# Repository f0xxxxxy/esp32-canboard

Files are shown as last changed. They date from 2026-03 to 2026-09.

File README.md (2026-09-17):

# ESP32-CANBoard
* ESP32-S3 Dual Core SoC
* MCP2562T CAN Transceiver (up to 1Mbps)
* 16x 5V tolerant analog inputs via 2x ADS7830 I2C expanders.
* Optional pull-up resistors via fused 5V rail for each input (TH 6.3mm).
* 3x 5V power output pins for digital sensors.
  * 500ma self-resetting thermal fuse.
  * Output pins and pull-up rail only active with external power present, not USB.
* USB-C for programming, with JTAG support for debugging.
* ESD Protection on both USB and CAN, with reverse polarity protection on power input.
* TE Connectivity AMP 26 Way Superseal Connector.
  * PCB Socket: 9-6437287-8
  * Cable Plug: 3-1437290-7
* Internal 5V rail reference for accurate output calculation when pull-up in use.
* Configuration via web interface over WiFi, with backup and restore functionality.
* Optional per-channel median filtering with selectable strength (none/low/med/high) to reduce noise.

## Device Configuration

On each boot the board enables a WiFi access point and web configuration interface; this will automatically disable after 120 seconds if no client connects.

| SSID | WPA2 Key | Web UI |
|:---|:---|:---|
| ESP32-CanBoard | canboard123 | http://192.168.4.1 |

The web UI allows you to:

- View and edit per-channel settings (name, sensor type, pull-up, pressure unit, filter level, voltage and pressure calibration).
- Configure required base CAN parameters - ID and bus speed.
- View current 5V rail reference, input voltages and calculated values in real time when external power is connected.
- Backup and restore the entire configuration to or from a JSON file.

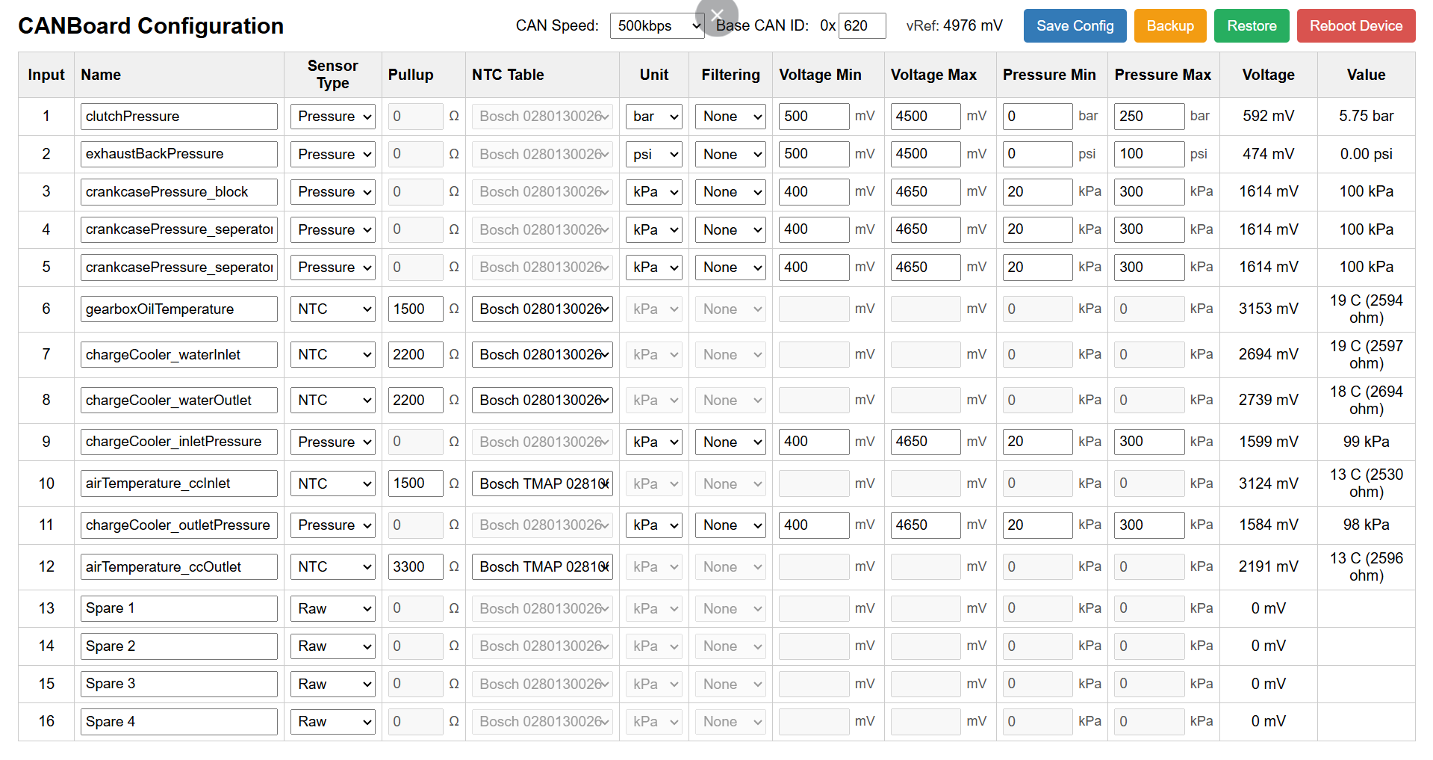
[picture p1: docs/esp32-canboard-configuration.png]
esp32-canboard-configuration


| Function | Description |
|:----|:----|
| Save Config | Save current UI settings to device storage (`/spiffs/config.bin`). Changes are validated, persisted and applied immediately. |
| Backup | Download a JSON snapshot of the current configuration. The filename is prefixed with `esp32-canboard-config-` and suffixed with the client timestamp in `ddmmyy-hhmmss` format. |
| Restore | Select a previously exported JSON file. The UI will upload the JSON to the device and validate the payload. The existing configuration is backed up on the device before overwrite; if saving the imported file fails, the device will restore the previous configuration. |
| Reboot Device | Reboots the device. |

**Notes:**
- Configuration is persisted on SPIFFS at `/spiffs/config.bin` (binary) and the web UI uses JSON export/import for human-readable backups.

## CAN Output

The device transmits input data as a set of eight CAN frames starting at the configured base ID. All frames use DLC8 and little-endian byte ordering.

Overview:
- Frames 0..3 (Base ID .. Base ID+3): packed analog voltages for all 16 channels, 4 channels per frame, each channel as uint16 (millivolts, LSB then MSB).
- Frames 4..7 (Base ID+4 .. Base ID+7): packed dynamic values for all 16 channels, 4 values per frame, each as uint16. Dynamic values are sensor-type dependent (zeros where not applicable).

Detailed layout:

| CAN ID | Contents |
|:---|:---|
| Base ID + 0 | Channels 0..3 → ch0 (bytes 0..1 LSB/MSB), ch1 (2..3), ch2 (4..5), ch3 (6..7) — analog mV uint16 |
| Base ID + 1 | Channels 4..7 — analog mV uint16 |
| Base ID + 2 | Channels 8..11 — analog mV uint16 |
| Base ID + 3 | Channels 12..15 — analog mV uint16 |
| Base ID + 4 | Dynamic 0..3 — per-channel dynamic outputs (uint16) |
| Base ID + 5 | Dynamic 4..7 — per-channel dynamic outputs (uint16) |
| Base ID + 6 | Dynamic 8..11 — per-channel dynamic outputs (uint16) |
| Base ID + 7 | Dynamic 12..15 — per-channel dynamic outputs (uint16) |

Encoding rules for dynamic values (one per input):
| Type | Encoding |
|:---|:---|
| Raw | uint16 = 0 (no dynamic output; use analog voltage frame) |
| Pressure | uint16 = pressure * 100 (resolution 0.01 [bar, psi, kPa]) |
| NTC | signed int16 = temperature_C (°C as integer) stored in uint16 (least-significant 16 bits) |

Receivers should interpret all measurement values as little-endian uint16s unless noted. Dynamic outputs use live V5 for conversions where applicable.

Example DBC for signal names and scaling: [dbc/esp32-canboard.dbc](dbc/esp32-canboard.dbc)

## Schematic
[View PDF](hardware/esp32-canboard-schematic.pdf)

## Images
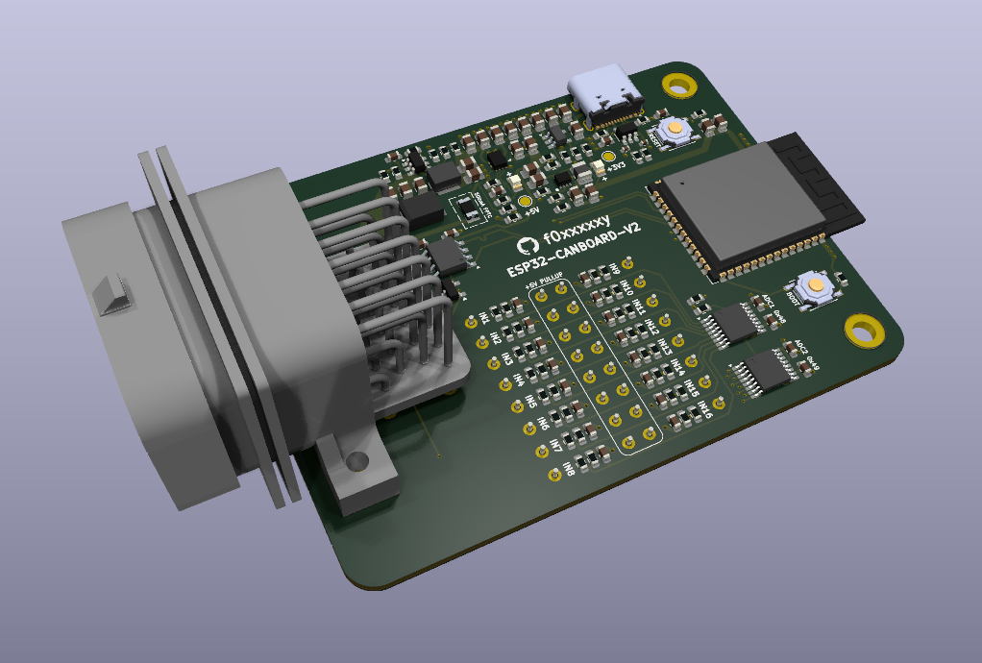
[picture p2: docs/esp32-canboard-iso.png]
esp32-canboard-iso


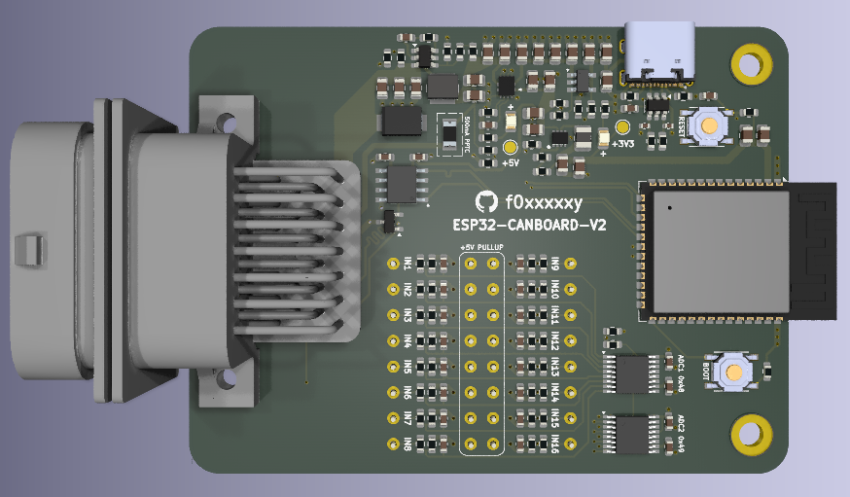
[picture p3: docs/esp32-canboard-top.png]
esp32-canboard-top


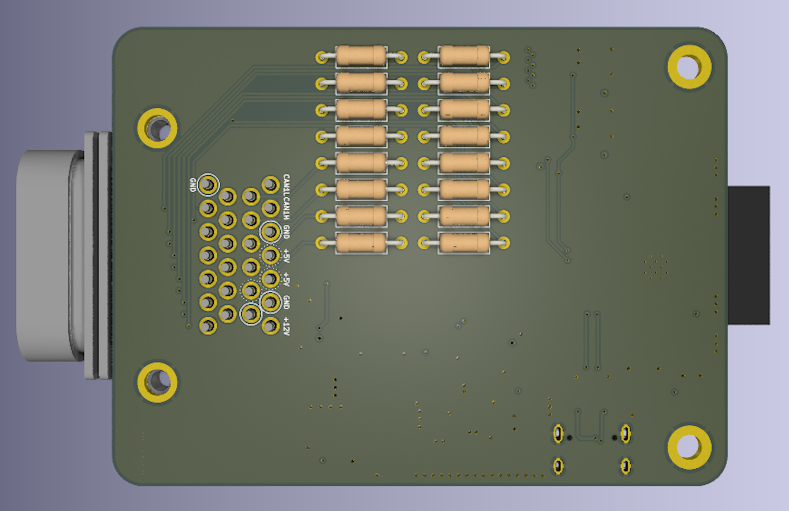
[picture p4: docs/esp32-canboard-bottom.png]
esp32-canboard-bottom


## Connector Pinout
|Pin|Function|Additional Information|
|:---:|:---|:---|
|1|12v Supply||
|2|Ground||
|3|5v Sensor Supply|500ma Thermal Fuse|
|4|5v Sensor Supply|500ma Thermal Fuse|
|5|Ground||
|6|CAN High||
|7|CAN Low||
|8|Ground||
|9|5v Sensor Supply|500ma Thermal Fuse|
|10|Input 1||
|11|Input 2||
|12|Input 3||
|13|Input 4||
|14|Input 5||
|15|Input 6||
|16|Input 7||
|17|Input 8||
|18|Input 9||
|19|Input 10||
|20|Input 11||
|21|Input 12||
|22|Input 13||
|23|Input 14||
|24|Input 15||
|25|Input 16||
|26|Ground||

## Disclaimer

This product has been designed by a hobbyist, not a professional. Users should operate the product at their own discretion and risk. It is intended for testing and off-road use only. The designer explicitly disclaims any responsibility for damage or injury that may result from the use of this product.

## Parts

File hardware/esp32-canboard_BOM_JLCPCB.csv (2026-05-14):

Designator | Comment | Footprint | LCSC
C1,C2,C7,C36,C39,C40,C41 | 10uF | Capacitor_SMD:C_0805_2012Metric | C15850
C3,C8,C34,C37,C38,C42,C43,C45,C47 | 100nF | Capacitor_SMD:C_0805_2012Metric | C49678
C4,C9,C10,C12,C14,C15,C16,C17,C18,C19,C20,C21,C22,C23,C24,C25,C26,C27,C28,C29,C30,C31,C32,C44,C49,C50 | 100nF | Capacitor_SMD:C_0603_1608Metric | C14663
C5,C6,C33,C35,C46,C48 | 22uF | Capacitor_SMD:C_0805_2012Metric | C45783
C11,C13 | 10pF | Capacitor_SMD:C_0402_1005Metric | C32949
CONN2 | KH-TYPE-C-16P | KH-TYPE-C-16P:KINGHELM_KH-TYPE-C-16P | C709357
D1 | SMBJ24A | DIOM5436X244N | C87268
ESD1 | USBLC6-2SC6 | Package_TO_SOT_SMD:SOT-23-6 | C7519
ESD2 | NUP2105LT1G | Package_TO_SOT_SMD:SOT-23-3 | C2890118
F1 | 1206L050YR | 1206L050YR:1206L05015YR | C163512
IC1 | MCP2562T-E_SN | MCP2562T-E_SN:SOIC127P600X175-8N | C191417
IC2,IC3 | ADS7830IPWR | SOP65P640X120-16N | C161747
IC4 | SY6280AAC | SOT95P285X140-5N | C55136
IC5 | TPS2121RUXR | TPS2121RUXR | C485916
IC6 | TPS62823DLCR | SON50P150X200X100-8N | C2693497
L1 | 5.6uH | SMNR4020-5R6MT:SMNR4020-5R6MT | C467062
L2 | 470nH | Inductor_SMD:L_1008_2520Metric | C5289268
LED1 | 0805_Red | LED_SMD:LED_0805_2012Metric | C84256
LED3 | 0805_Green | LED_SMD:LED_0805_2012Metric | C2297
R1 | 33R | Resistor_SMD:R_0603_1608Metric | C23140
R2 | 13K | Resistor_SMD:R_0603_1608Metric | C22797
R3,R6,R8,R9,R16,R20,R23,R26,R29,R40,R41,R42,R43,R44,R49,R52,R55,R58,R61,R64,R65 | 10K | Resistor_SMD:R_0603_1608Metric | C25804
R4 | 100K | Resistor_SMD:R_0603_1608Metric | C25803
R5 | 300K | Resistor_SMD:R_0603_1608Metric | C23024
R10 | 8K2 | Resistor_SMD:R_0603_1608Metric | C25981
R11,R12 | 22R | Resistor_SMD:R_0603_1608Metric | C23345
R13,R14,R15,R19,R22,R25,R28,R35,R36,R37,R38,R39,R48,R51,R54,R57,R60,R63 | 5K1 | Resistor_SMD:R_0603_1608Metric | C23186
R45,R46 | 3K3 | Resistor_SMD:R_0603_1608Metric | C22978
R66 | 47K | Resistor_SMD:R_0603_1608Metric | C25819
R67 | 7K5 | Resistor_SMD:R_0603_1608Metric | C23234
R68,R74 | 33K | Resistor_SMD:R_0603_1608Metric | C4216
R69 | 68K | Resistor_SMD:R_0603_1608Metric | C23231
R70 | 1K8 | Resistor_SMD:R_0603_1608Metric | C4177
R71 | 150K | Resistor_SMD:R_0603_1608Metric | C22807
R72 | 120R | Resistor_SMD:R_0603_1608Metric | C22787
R73 | 39K | Resistor_SMD:R_0603_1608Metric | C23153
R75 | 18K | Resistor_SMD:R_0603_1608Metric | C25810
SW1 | BOOT | TS-1187A-B-A-B:SW_TS-1187A-B-A-B | C318884
SW2 | RESET | TS-1187A-B-A-B:SW_TS-1187A-B-A-B | C318884
U1 | TPS56339DDCR | Package_TO_SOT_SMD:SOT-23-6 | C2071106

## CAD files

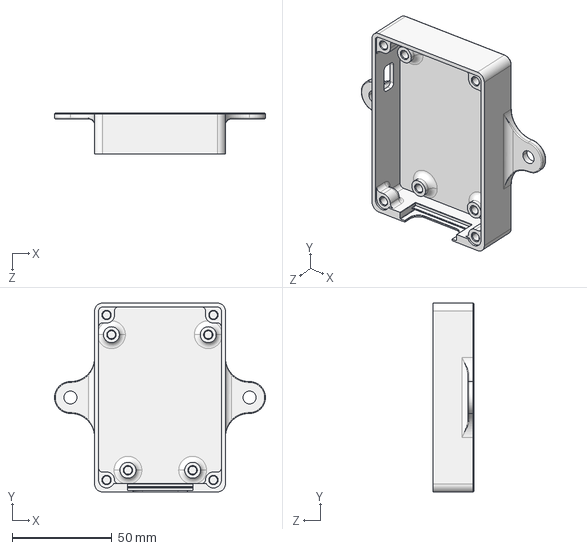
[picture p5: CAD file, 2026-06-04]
hardware/case/esp32-canboard-case-bottom.STEP
106.0 x 94.9 x 20.5 mm

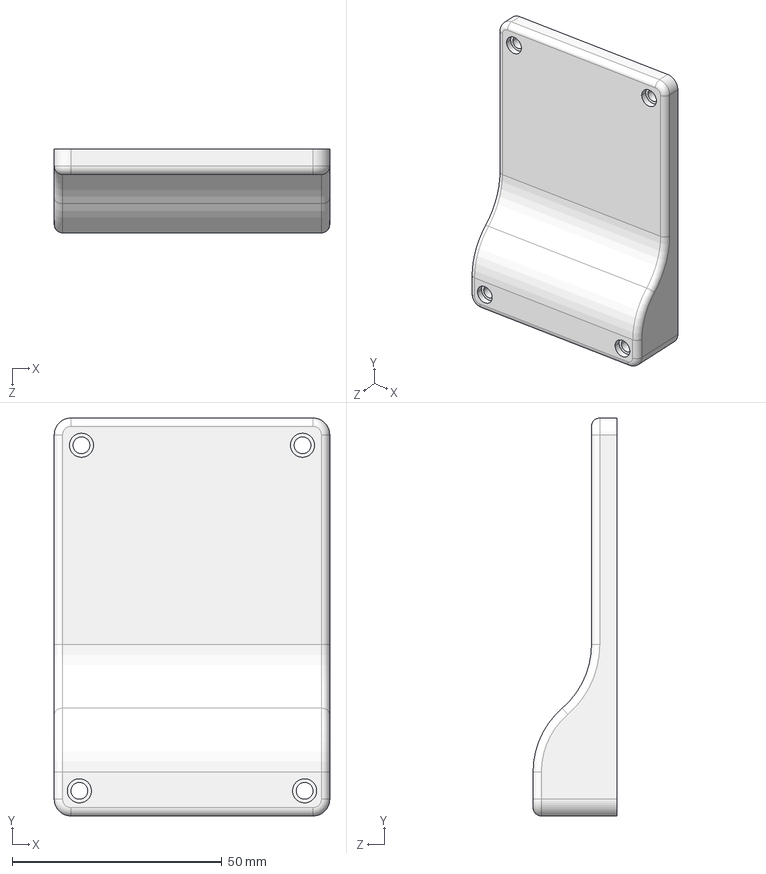
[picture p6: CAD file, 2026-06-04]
hardware/case/esp32-canboard-case-top.STEP
65.7 x 94.9 x 20.0 mm

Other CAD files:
hardware/case/esp32-canboard-case-bottom.STL
hardware/case/esp32-canboard-case-top.STL

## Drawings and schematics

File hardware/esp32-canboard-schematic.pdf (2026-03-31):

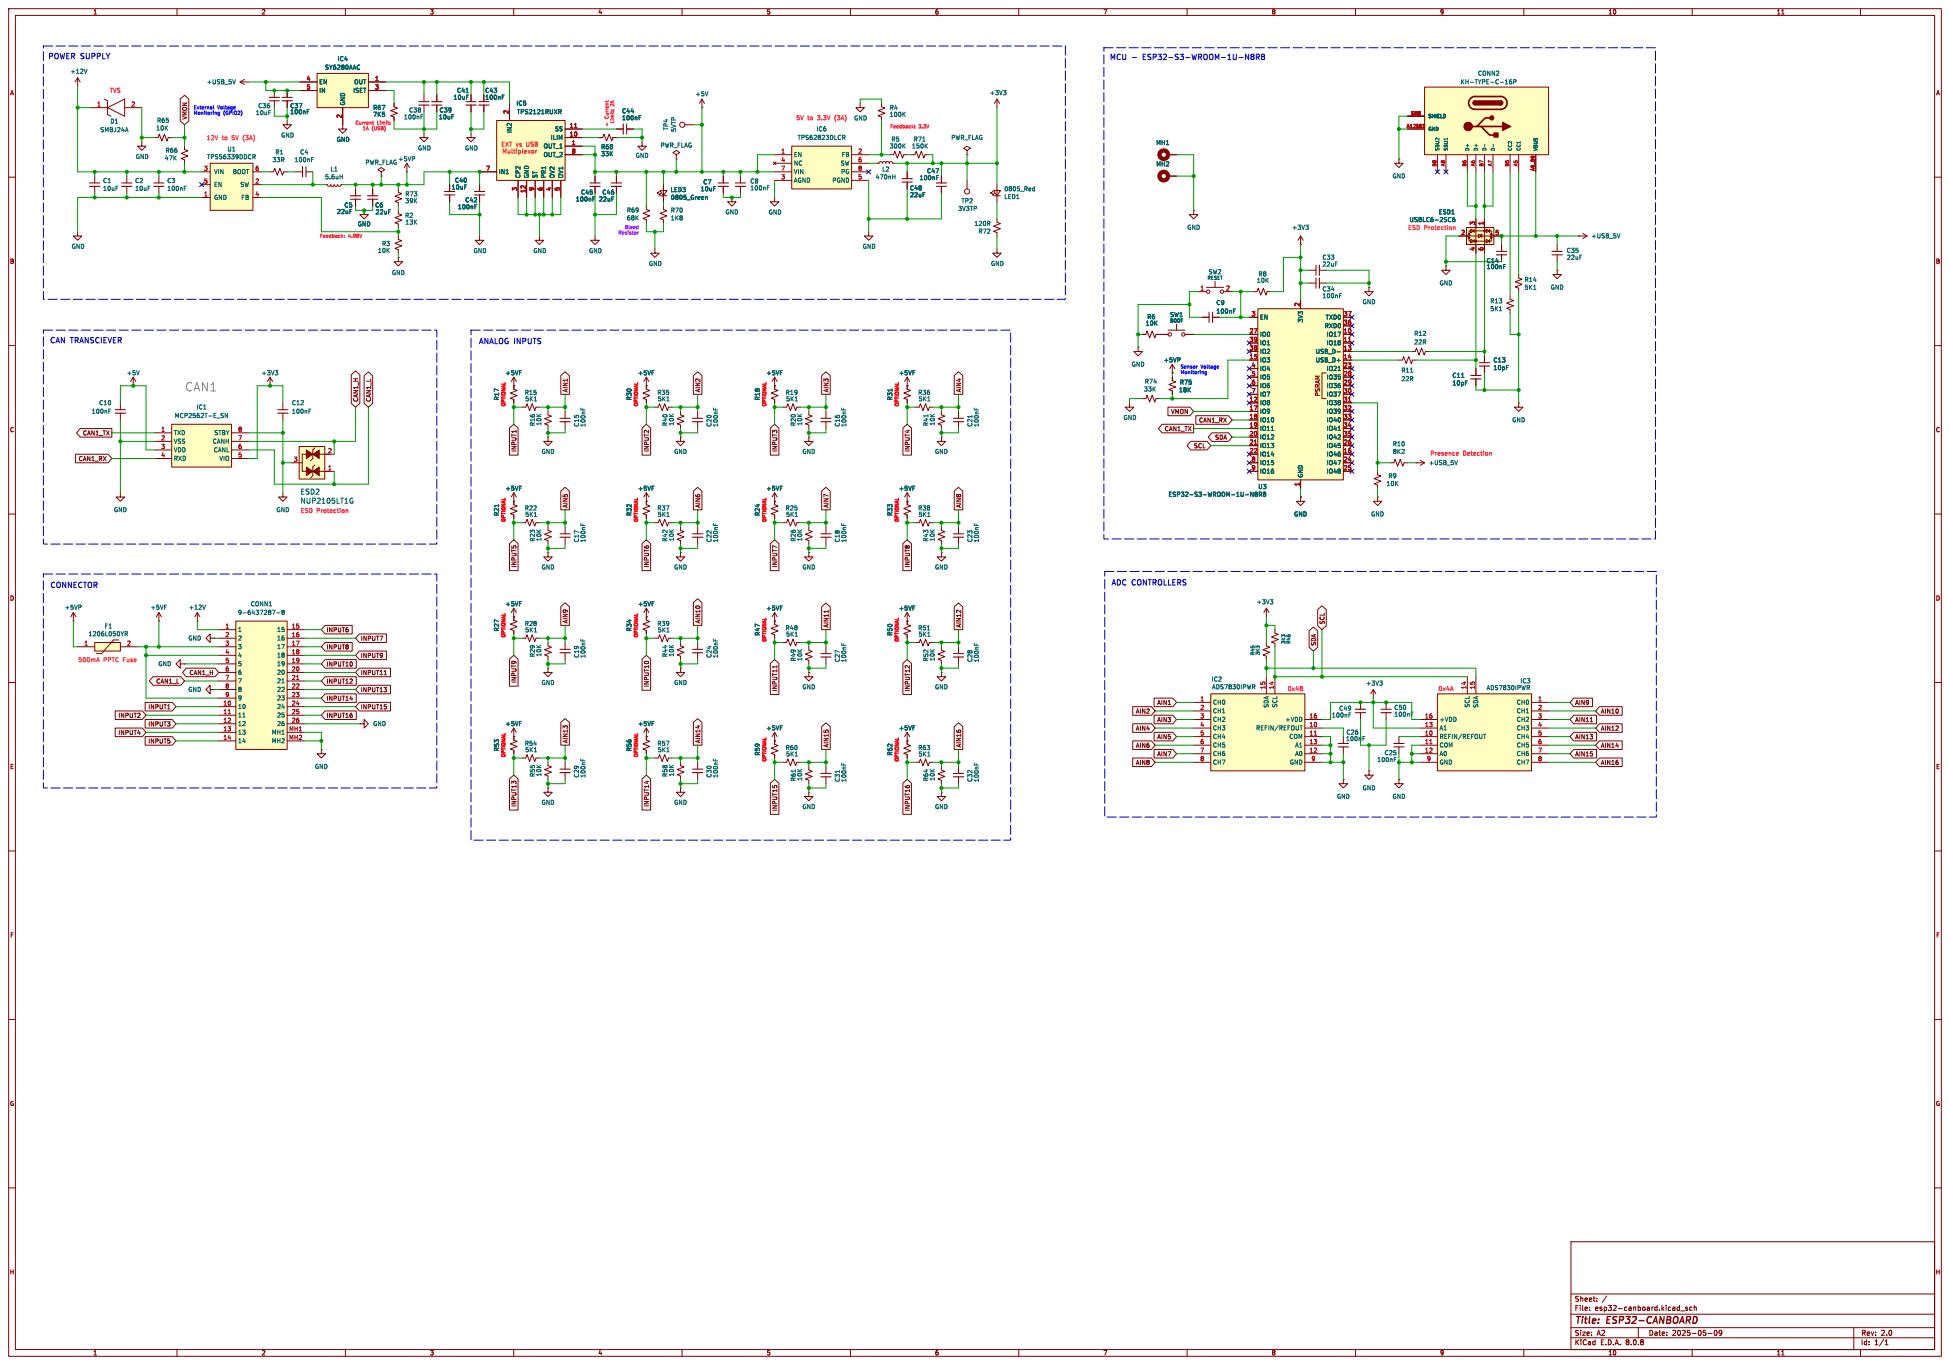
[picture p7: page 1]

Sensor Voltage Monitoring þÿ!•Current Limit: 2A

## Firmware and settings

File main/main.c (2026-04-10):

#include <stdio.h>
#include <stdlib.h>
#include <stdbool.h>
#include <stddef.h>
#include <string.h>
#include <time.h>
#include <sys/time.h>

#include "freertos/FreeRTOS.h"
#include "freertos/task.h"
#include "freertos/semphr.h"

#include "esp_err.h"
#include "esp_log.h"
#include "esp_system.h"
#include "driver/gpio.h"
#include "esp_twai.h"

#define USB_PRESENCE_DETECT GPIO_NUM_38

#include "inc/inputs.h"
#include "inc/can.h"

#include "inc/wifi_config.h"
#include "inc/config.h"
#include "esp_spiffs.h"

#include "inc/i2c_master.h"

/** @brief Global board configuration shared across modules. */
board_config_t board_cfg;

/**
 * @brief Application entry point.
 *
 * Initializes persistent configuration, WiFi configuration mode, sensors,
 * ADC acquisition, CAN driver, and runtime tasks.
 */
void app_main(void)
{
    static const char *log_tag = "APP";
    
    // Mount SPIFFS first so config_load/config_save can access persisted data.
    esp_err_t spiffs_ret = esp_vfs_spiffs_register(&(esp_vfs_spiffs_conf_t){
        .base_path = "/spiffs",
        .partition_label = NULL,
        .max_files = 5,
        .format_if_mount_failed = true
    });
    if (spiffs_ret == ESP_ERR_INVALID_STATE) {
        ESP_LOGI(log_tag, "SPIFFS already mounted");
    } else if (spiffs_ret != ESP_OK) {
        ESP_LOGW(log_tag, "Failed to mount SPIFFS: %s", esp_err_to_name(spiffs_ret));
    } else {
        ESP_LOGI(log_tag, "SPIFFS mounted for config access");
    }
    if (!config_load(&board_cfg)) {
        ESP_LOGW(log_tag, "Config CRC invalid or not found, using defaults");
        config_set_defaults(&board_cfg);
        if (!config_save(&board_cfg)) {
            ESP_LOGE(log_tag, "Failed to save default config!");
        }
    } else {
        ESP_LOGI(log_tag, "Config loaded and CRC valid");
    }

    // Start WiFi configuration mode (AP + HTTP server with timeout).
    wifi_config_mode_start();
    
    // Initialize CPU temperature sensor.
    esp_err_t err = initCpuTempSensor();
    if (err != ESP_OK) {
        ESP_LOGW(log_tag, "Failed to initialize CPU temp sensor: %s", esp_err_to_name(err));
    } else {
        int8_t cpu_temp = getCpuTemperature();
        ESP_LOGI(log_tag, "Current CPU Temperature: %d°C", cpu_temp);
    }

    // Initialize ADC channels.
    initAdcChannels();

    // Initialize TWAI/CAN driver with speed from persisted config.
    if (can_init() != ESP_OK) {
        ESP_LOGE(log_tag, "Failed to initialize CAN driver!");
        abort();
    }

    // Create mutex protecting filtered voltage array.
    filtered_voltages_mutex = xSemaphoreCreateMutex();
    if (filtered_voltages_mutex == NULL) {
        ESP_LOGE(log_tag, "Failed to create voltage mutex! Aborting...");
        abort();
    }

    // Start ADC processing task on Core 1.
    BaseType_t task_result = xTaskCreatePinnedToCore(
        adcProcess, "adcProcess", 8192, NULL, 5, NULL, 1);
    if (task_result != pdPASS) {
        ESP_LOGE(log_tag, "Failed to create ADC processing task!");
        abort();
    }

    // Start CAN transmit task on Core 0.
    task_result = xTaskCreatePinnedToCore(
        canTransmit, "canTransmit", 8192, NULL, 10, NULL, 0);
    if (task_result != pdPASS) {
        ESP_LOGE(log_tag, "Failed to create CAN transmit task!");
        abort();
    }
    
    ESP_LOGI(log_tag, "System initialization complete");
}

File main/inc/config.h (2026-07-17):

#ifndef CONFIG_H
#define CONFIG_H

#include <stdint.h>
#include <stdbool.h>

#define CONFIG_CHANNELS 16       ///< Number of ADC input channels.
#define CONFIG_NAME_LEN 32       ///< Maximum characters for channel name.
#define CONFIG_VERSION 6         ///< Configuration structure version number.

/** @brief Pressure units selectable in UI and stored per-channel. */
typedef enum {
    UNIT_KPA = 0,
    UNIT_BAR = 1,
    UNIT_PSI = 2
} pressure_unit_t;

/**
 * @brief Per-channel median filter strength levels.
 * Stored in the 8-bit filtering field below.
 * 0 = none, 1 = low (5-sample), 2 = medium (10-sample), 3 = high (15-sample).
 */
typedef enum {
    FILTER_NONE = 0,
    FILTER_LOW  = 1,
    FILTER_MED  = 2,
    FILTER_HIGH = 3
} filter_level_t;

/** @brief Sensor measurement types for ADC channels. */
typedef enum {
    SENSOR_RAW = 0,
    SENSOR_NTC = 1,
    SENSOR_PRESSURE = 2
} sensor_type_t;

/** @brief Per-channel configuration structure. */
typedef struct {
    char name[CONFIG_NAME_LEN]; ///< ASCII name/description of the channel.
    uint32_t pullup_ohms;       ///< Optional pullup resistor value in ohms (0 if not present).
    sensor_type_t type;         ///< Sensor type (RAW, NTC, PRESSURE).
    uint8_t filtering;          ///< Median filter level (see filter_level_t enum).
    union {
        struct { ///< NTC thermistor configuration.
            uint8_t table_id;   ///< Reference table index for NTC lookup.
        } ntc;
        struct { ///< Pressure sensor configuration.
            uint16_t min_mv;    ///< Minimum voltage in millivolts.
            uint16_t max_mv;    ///< Maximum voltage in millivolts.
            float min_kpa;      ///< Minimum pressure in kilopascals.
            float max_kpa;      ///< Maximum pressure in kilopascals.
            uint8_t pressure_unit; ///< Unit enum (pressure_unit_t).
        } pressure;
        struct { ///< Raw voltage measurement (no conversion).
        } raw;
    } params;
} channel_config_t;

/** @brief Main board configuration structure persisted to SPIFFS. */
typedef struct {
    uint32_t version;                      ///< Config version for migration/compatibility.
    uint32_t can_start_id;                 ///< CAN message ID base (incremented for each message).
    uint32_t can_speed_kbps;               ///< CAN bus speed (125, 250, 500, or 1000 kbps).
    uint8_t can_tx_hz;                     ///< CAN transmit loop rate in Hz (supported: 25 or 50).
    channel_config_t channels[CONFIG_CHANNELS]; ///< Per-channel configuration array.
    uint32_t crc32;                        ///< CRC32 checksum of all fields above.
} board_config_t;

/**
 * @brief Persist board configuration to SPIFFS with CRC32 verification.
 * @param cfg Pointer to configuration structure to save.
 * @return true on success; false on persistence error.
 */
bool config_save(const board_config_t *cfg);

/**
 * @brief Load and validate board configuration from SPIFFS.
 * @param cfg Pointer to configuration structure to populate.
 * @return true when data is loaded and valid; false on error or invalid CRC.
 */
bool config_load(board_config_t *cfg);

/**
 * @brief Initialize configuration structure with factory defaults.
 * @param cfg Pointer to configuration structure to initialize.
 */
void config_set_defaults(board_config_t *cfg);

#endif // CONFIG_H

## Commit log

2026-02-22 Fix vref loading from config.
    [http_server.c]
2026-02-23 UI changes and remove reboot requirement.
    [http_server.c]
2026-02-27 Selectable filtering levels
2026-03-19 Merge: rebase v2-hardware onto v2 and apply ADS7830/I2C/http API changes
2026-03-31 Update example DBC.
    [esp32-canboard-case-bottom.STL, esp32-canboard-case-top.STL, esp32-canboard.kicad_pcb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]
2026-04-03 Misc ADC changes.
2026-04-03 ADC calculation changes.
2026-04-04 ADC Scaling Fixes
2026-04-04 ADC adjustments.
2026-04-10 Add connector pinout.
2026-04-12 UI pressure conversion bug.
2026-05-14 Add hardware.
    [esp32-canboard-case-bottom.STL, esp32-canboard-case-top.STL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]
2026-06-04 Add case STEP files.
    [esp32-canboard-case-bottom.STEP, esp32-canboard-case-top.STEP]
2026-07-30 Fix NTC calculation offset.
    [http_server.c, inputs.c, inputs.h]
2026-09-02 Adjust 0281002437 Calibration
